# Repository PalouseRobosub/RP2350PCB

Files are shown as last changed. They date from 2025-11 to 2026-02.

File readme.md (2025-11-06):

## Rp2350 PCB
PCB for using the Rp2350 over CAN, exposing GPIO and ADC pins, designed in KiCAD v9

Current revision is a prototype for verifying we can actually hand assemble all the parts, hence the use of a linear regulator and dense size for optimizing cost.
Next revision will likely be bigger and use a switching regulator.

Designed for OshPark design rules at https://docs.oshpark.com/design-tools/kicad/kicad-design-rules/

Please refer to Library/LibraryReference.md for component attribution

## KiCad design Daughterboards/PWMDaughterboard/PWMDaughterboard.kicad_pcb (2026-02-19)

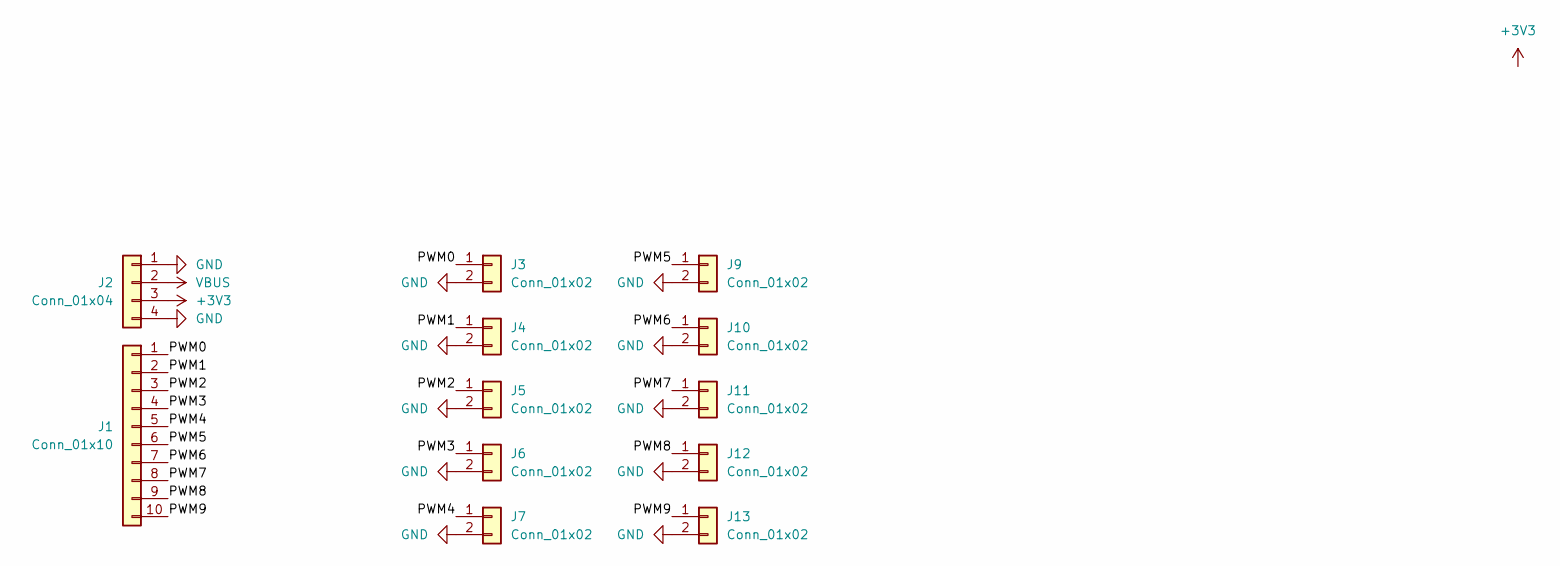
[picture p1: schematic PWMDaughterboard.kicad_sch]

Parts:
J1: Conn_01x10; PinHeader_1x10_P2.00mm_Vertical_SMD_Pin1Left
J2: Conn_01x04; PinHeader_1x04_P2.00mm_Vertical_SMD_Pin1Left
J3, J4, J5, J6, J7, J9, J10, J11, J12, J13: Conn_01x02; JST_GH_BM02B-GHS-TBT_1x02-1MP_P1.25mm_Vertical

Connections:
+3V3: J2.3
/PWM0: J1.1, J3.1
/PWM1: J1.2, J4.1
/PWM2: J1.3, J5.1
/PWM3: J1.4, J6.1
/PWM4: J1.5, J7.1
/PWM5: J1.6, J9.1
/PWM6: J1.7, J10.1
/PWM7: J1.8, J11.1
/PWM8: J1.9, J12.1
/PWM9: J1.10, J13.1
GND: J2.1, J2.4, J3.2, J4.2, J5.2, J6.2, J7.2, J9.2, J10.2, J11.2, J12.2, J13.2
VBUS: J2.2

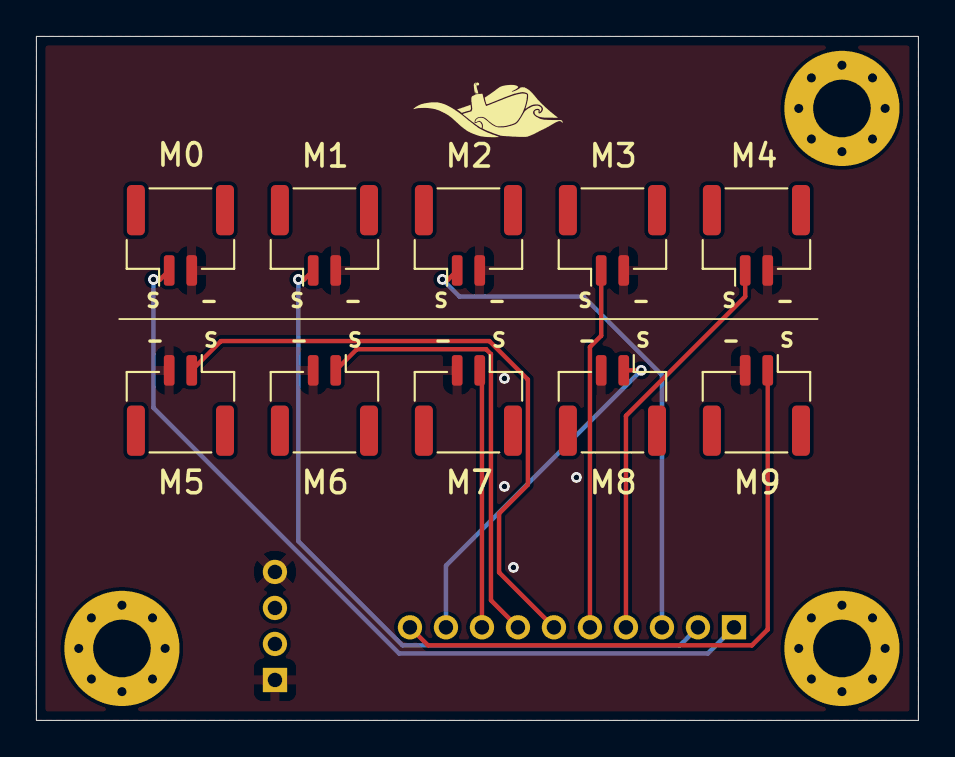
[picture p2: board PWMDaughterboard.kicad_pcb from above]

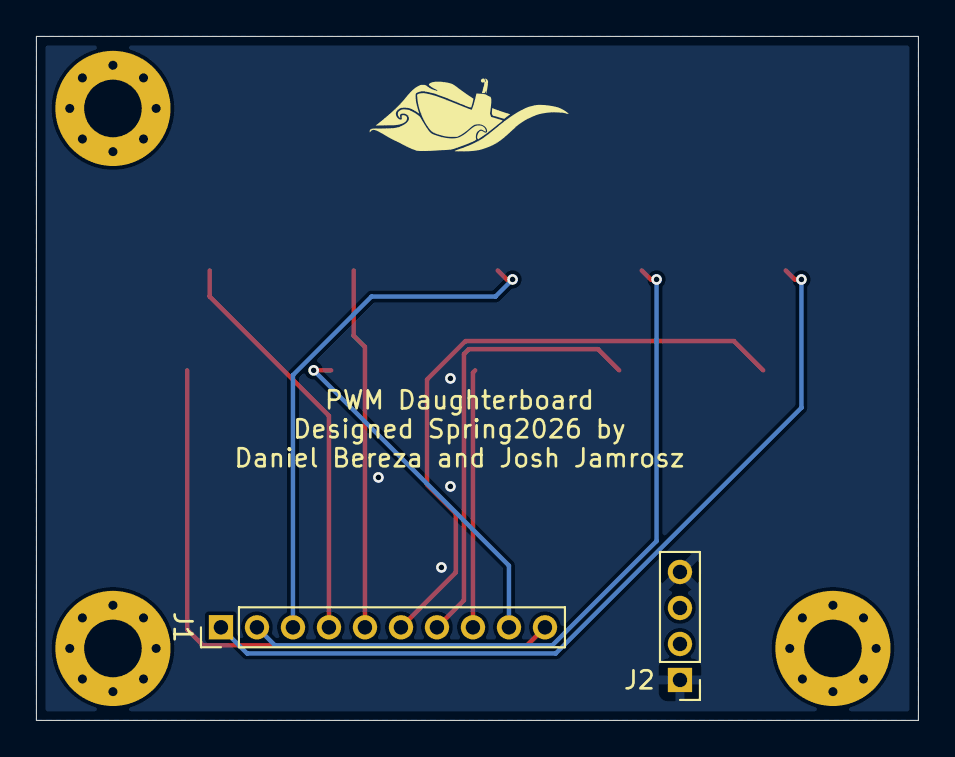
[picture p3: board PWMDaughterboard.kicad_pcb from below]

Board: 2 copper layers, 49.0 x 38.0 mm, 12 parts (2 on the bottom side), 11 nets.

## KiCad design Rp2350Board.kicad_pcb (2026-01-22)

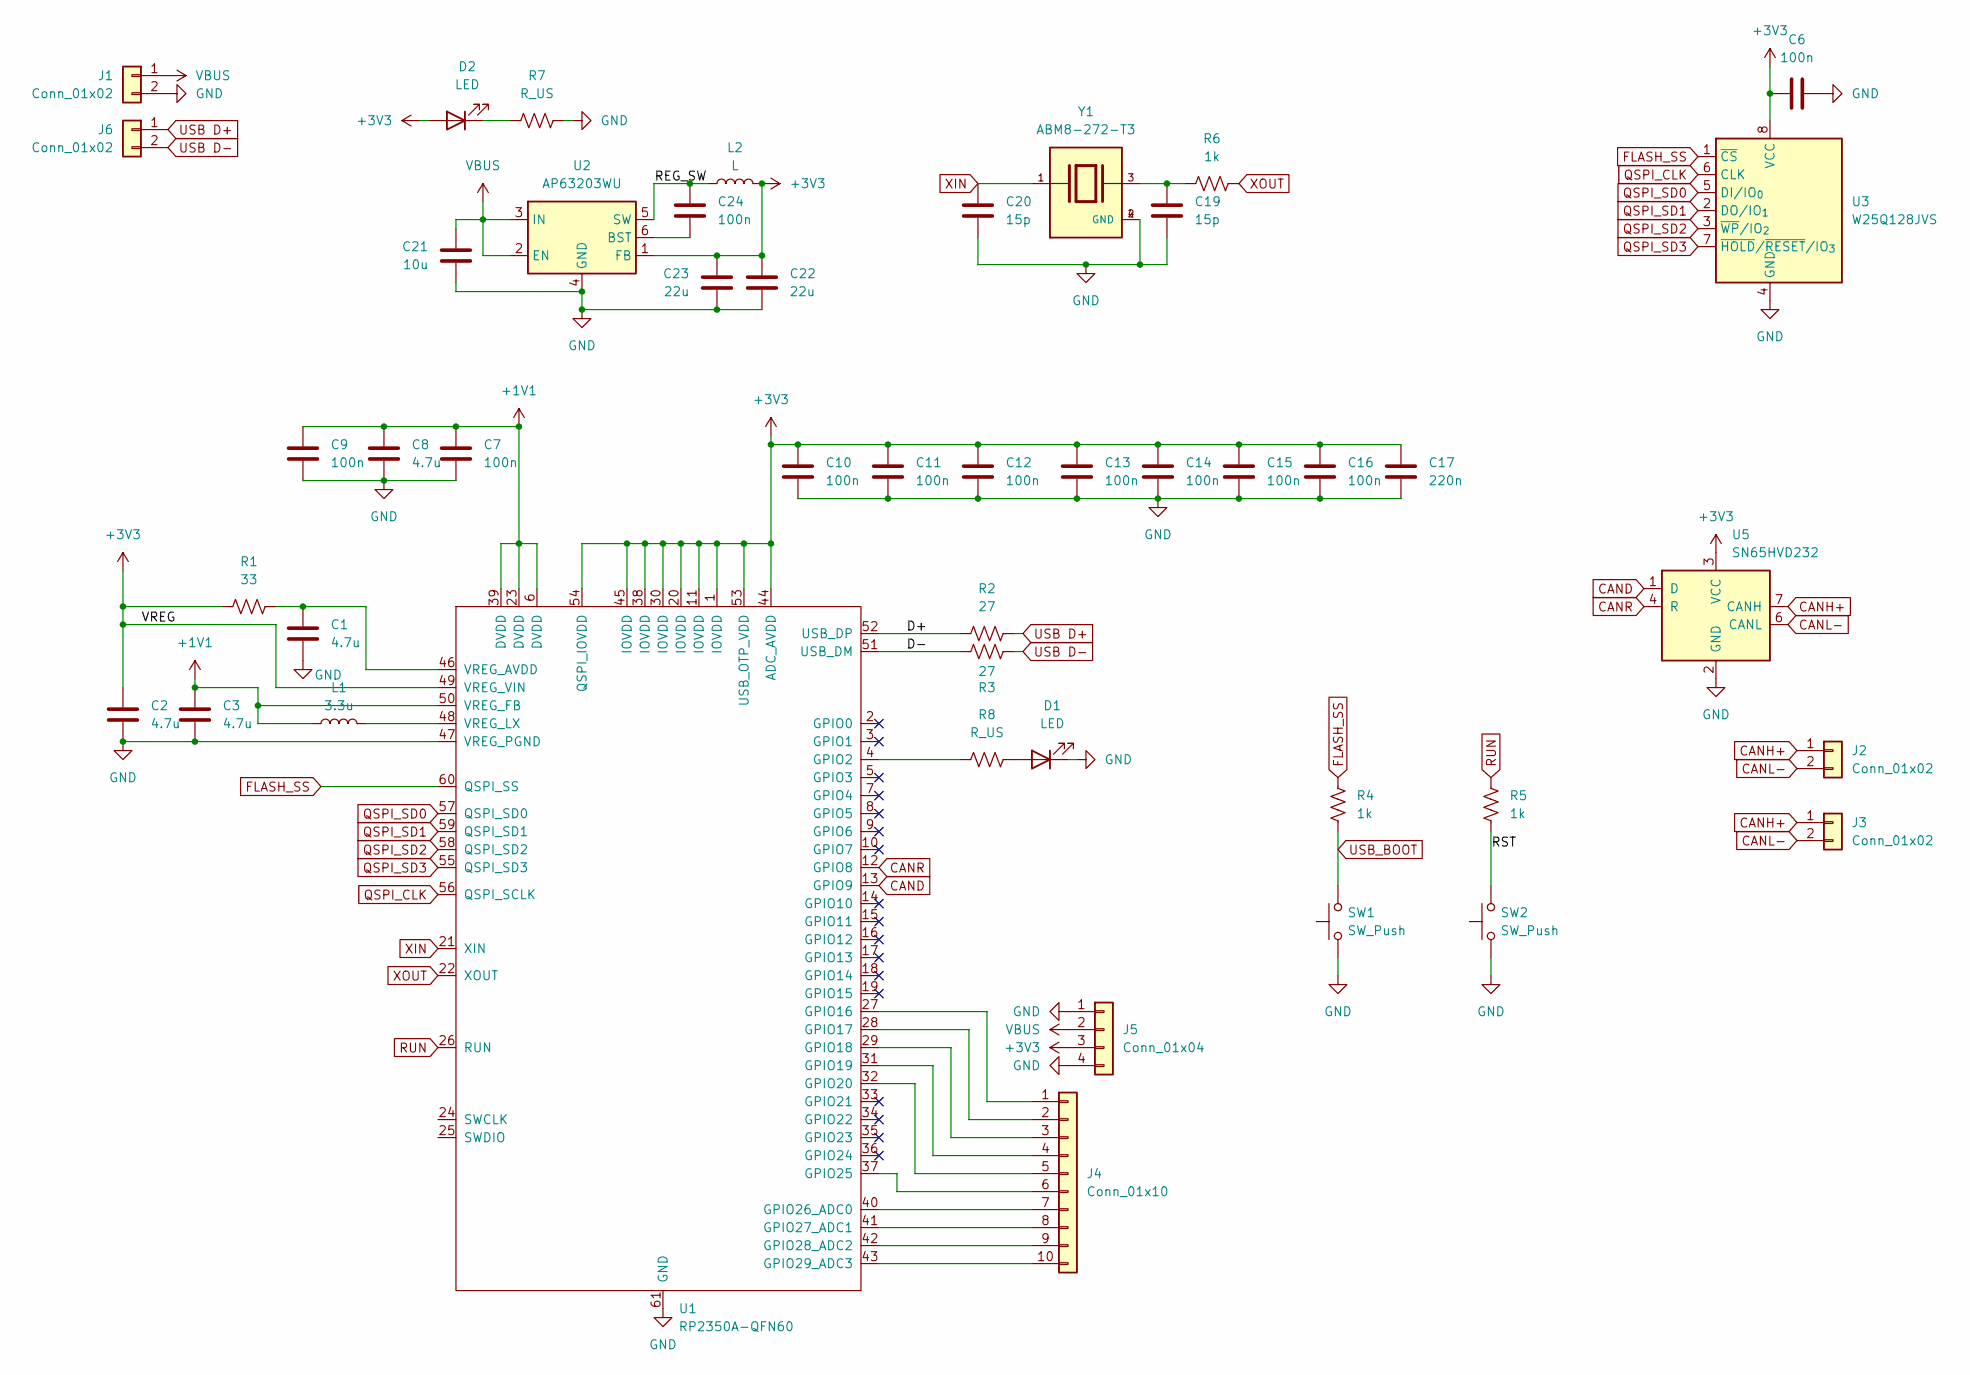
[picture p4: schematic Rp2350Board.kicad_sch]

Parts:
C1, C2, C3, C8: 4.7u; C_0603_1608Metric
C6, C7, C9, C10, C11, C12, C13, C14, C15, C16, C24: 100n; C_0603_1608Metric
C17: 220n; C_0603_1608Metric
C19, C20: 15p; C_0603_1608Metric
C21: 10u; C_0603_1608Metric
C22, C23: 22u; C_0603_1608Metric
D1, D2: LED; LED_0603_1608Metric
J1, J2, J3, J6: Conn_01x02; JST_GH_SM02B-GHS-TB_1x02-1MP_P1.25mm_Horizontal
J4: Conn_01x10; PinSocket_1x10_P2.00mm_Vertical_SMD_Pin1Left
J5: Conn_01x04; PinSocket_1x04_P2.00mm_Vertical_SMD_Pin1Left
L1: 3.3u; AOTAB201610S3R3101T
L2: L; PA5430
R1: 33; R_0603_1608Metric
R2, R3: 27; R_0603_1608Metric
R4, R5, R6: 1k; R_0603_1608Metric
R7, R8: R_US; R_0603_1608Metric
SW1, SW2: SW_Push; SW_EVQ-P7A01P
U1: RP2350A-QFN60; RP2350A_QFN-60_EP_7.75x7.75_Pitch0.4mm
U2: AP63203WU; TSOT-23-6
U3: W25Q128JVS; SOIC-8_5.3x5.3mm_P1.27mm
U5: SN65HVD232; SOIC-8_3.9x4.9mm_P1.27mm
Y1: ABM8-272-T3; XTAL_ABM8-272-T3; PARTREV 07-29-20

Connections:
+1V1: C3.1, C7.1, C8.1, C9.1, L1.1, U1.6 (DVDD), U1.23 (DVDD), U1.39 (DVDD), U1.50 (VREG_FB)
+3V3: C2.1, C6.2, C10.1, C11.1, C12.1, C13.1, C14.1, C15.1, C16.1, C17.1, C22.2, C23.1, D2.2 (A), J5.3, L2.2, R1.1, U1.1 (IOVDD), U1.11 (IOVDD), U1.20 (IOVDD), U1.30 (IOVDD), U1.38 (IOVDD), U1.44 (ADC_AVDD), U1.45 (IOVDD), U1.49 (VREG_VIN), U1.53 (USB_OTP_VDD), U1.54 (QSPI_IOVDD), U2.1 (FB), U3.8 (VCC), U5.3 (VCC)
/D+: R2.1, U1.52 (USB_DP)
/D-: R3.1, U1.51 (USB_DM)
/REG_SW: C24.1, L2.1, U2.5 (SW)
/RST: R5.1, SW2.2_1 (2)
CAND: U1.13 (GPIO9), U5.1 (D)
CANH+: J2.1, J3.1, U5.7 (CANH)
CANL-: J2.2, J3.2, U5.6 (CANL)
CANR: U1.12 (GPIO8), U5.4 (R)
FLASH_SS: R4.1, U1.60 (QSPI_SS), U3.1 (~CS)
GND: C1.2, C2.2, C3.2, C6.1, C7.2, C8.2, C9.2, C10.2, C11.2, C12.2, C13.2, C14.2, C15.2, C16.2, C17.2, C19.2, C20.2, C21.2, C22.1, C23.2, D1.1 (K), J1.2, J5.1, J5.4, R7.2, SW1.1_1, SW2.1_1, U1.47 (VREG_PGND), U1.61 (GND), U2.4 (GND), U3.4 (GND), U5.2 (GND), Y1.2 (GND), Y1.4 (GND)
unnamed: C19.1, R6.1, Y1.3
unnamed: D1.2 (A), R8.2
unnamed: D2.1 (K), R7.1
unnamed: J4.1, U1.27 (GPIO16)
unnamed: J4.2, U1.28 (GPIO17)
unnamed: J4.3, U1.29 (GPIO18)
unnamed: J4.4, U1.31 (GPIO19)
unnamed: J4.5, U1.32 (GPIO20)
unnamed: J4.6, U1.37 (GPIO25)
unnamed: J4.7, U1.40 (GPIO26_ADC0)
unnamed: J4.8, U1.41 (GPIO27_ADC1)
unnamed: J4.9, U1.42 (GPIO28_ADC2)
unnamed: J4.10, U1.43 (GPIO29_ADC3)
unnamed: R8.1, U1.4 (GPIO2)
unnamed: C1.1, R1.2, U1.46 (VREG_AVDD)
unnamed: L1.2, U1.48 (VREG_LX)
unnamed: C24.2, U2.6 (BST)
QSPI_CLK: U1.56 (QSPI_SCLK), U3.6 (CLK)
QSPI_SD0: U1.57 (QSPI_SD0), U3.5 (DI/IO_{0})
QSPI_SD1: U1.59 (QSPI_SD1), U3.2 (DO/IO_{1})
QSPI_SD2: U1.58 (QSPI_SD2), U3.3 (~WP/IO_{2})
QSPI_SD3: U1.55 (QSPI_SD3), U3.7 (~HOLD/~RESET/IO_{3})
RUN: R5.2, U1.26 (RUN)
USB D+: J6.1, R2.2
USB D-: J6.2, R3.2
USB_BOOT: R4.2, SW1.2_1 (2)
VBUS: C21.1, J1.1, J5.2, U2.2 (EN), U2.3 (IN)
XIN: C20.1, U1.21 (XIN), Y1.1
XOUT: R6.2, U1.22 (XOUT)

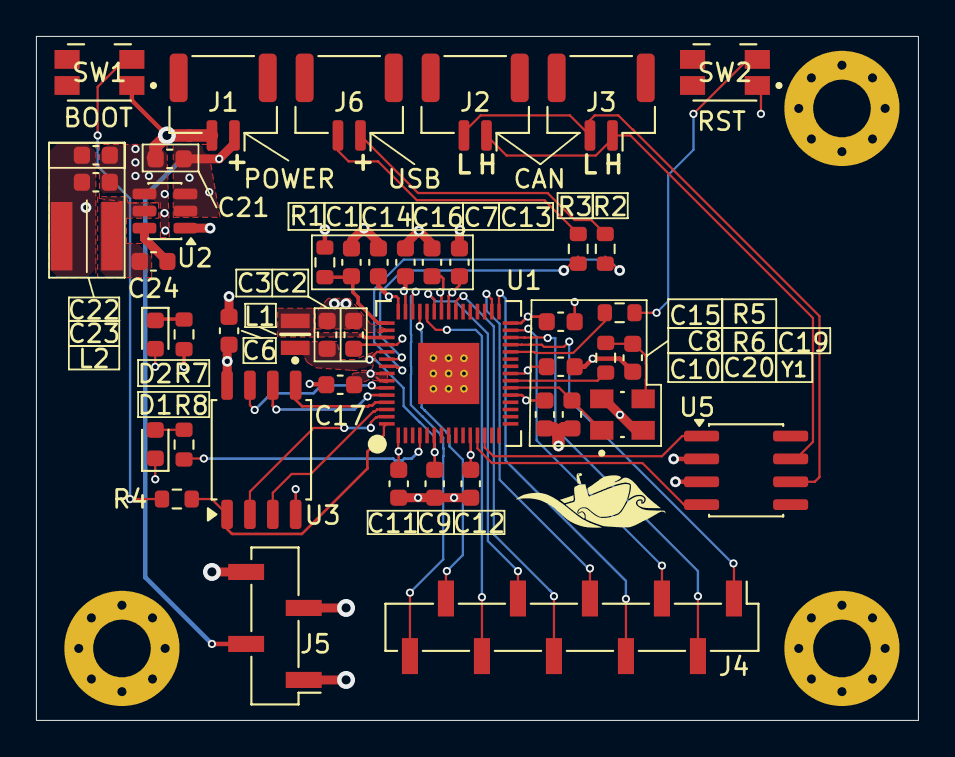
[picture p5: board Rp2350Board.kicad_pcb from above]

Board: 4 copper layers, 49.0 x 38.0 mm, 46 parts (0 on the bottom side), 41 nets.

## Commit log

2026-01-16 Fix mislabel
    [Rp2350Board.kicad_pcb]
2026-01-22 Added symbol, footprint, and model files for the PA5430
2026-01-22 First draft of v2 board
    [Rp2350Board.kicad_pcb, Rp2350Board.kicad_sch]
2026-01-22 Small edits to first draft of v2
    [Rp2350Board.kicad_pcb, Rp2350Board.kicad_sch]
2026-01-22 update AOTA inductor footprint
2026-01-22 Small fixups and cleanup of unused external library files
    [Rp2350Board.kicad_pcb, Rp2350Board.kicad_sch]
2026-02-09 Add PWM Daughterboard initial work
    [PWMDaughterboard.kicad_pcb, PWMDaughterboard.kicad_sch]
2026-02-10 Switched SMD headers J1,2 to through-hole
    [PWMDaughterboard.kicad_pcb]
2026-02-10 cleaned up vias
    [PWMDaughterboard.kicad_pcb]
2026-02-12 Added traces
    [PWMDaughterboard.kicad_pcb]
2026-02-19 Added silkscreen
    [PWMDaughterboard.kicad_pcb]
2026-02-19 Changed spacing
    [PWMDaughterboard.kicad_pcb]
2026-02-19 Size adjustment
    [PWMDaughterboard.kicad_pcb]
